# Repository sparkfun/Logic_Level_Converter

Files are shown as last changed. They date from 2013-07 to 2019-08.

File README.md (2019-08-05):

**NOTE:** *This product has been retired from our catalog. For a more up-to-date version, try looking at the [bi-directional logic level converter](https://www.sparkfun.com/products/12009).*

*If you are looking for more up-to-date info, please check out some of these resources to see how other users are still hacking and improving on this product.*

* *[SparkFun Forum](https://forum.sparkfun.com/)*
* *[Comments Here on GitHub](https://github.com/sparkfun/Logic_Level_Converter/issues)*
* *[IRC Channel](https://www.sparkfun.com/news/263)*

Logic Level Converter
=====================

Logic Level Converter (https://www.sparkfun.com/products/11978)

[*Logic Level Converter*](https://www.sparkfun.com/products/11978)

Design files for the [Logic Level Converter board](https://www.sparkfun.com/products/11978).

Repository Contents
-------------------

* **/hardware** - Eagle PCB layout files
* **/Production Files** - Files to support SparkFun production

Documentation
--------------
* **[Hookup Guide](https://learn.sparkfun.com/tutorials/retired---using-the-logic-level-converter)** - Basic hookup guide

License Information
-------------------

All contents of this repository are released under [Creative Commons Share-alike 3.0](http://creativecommons.org/licenses/by-sa/3.0/).

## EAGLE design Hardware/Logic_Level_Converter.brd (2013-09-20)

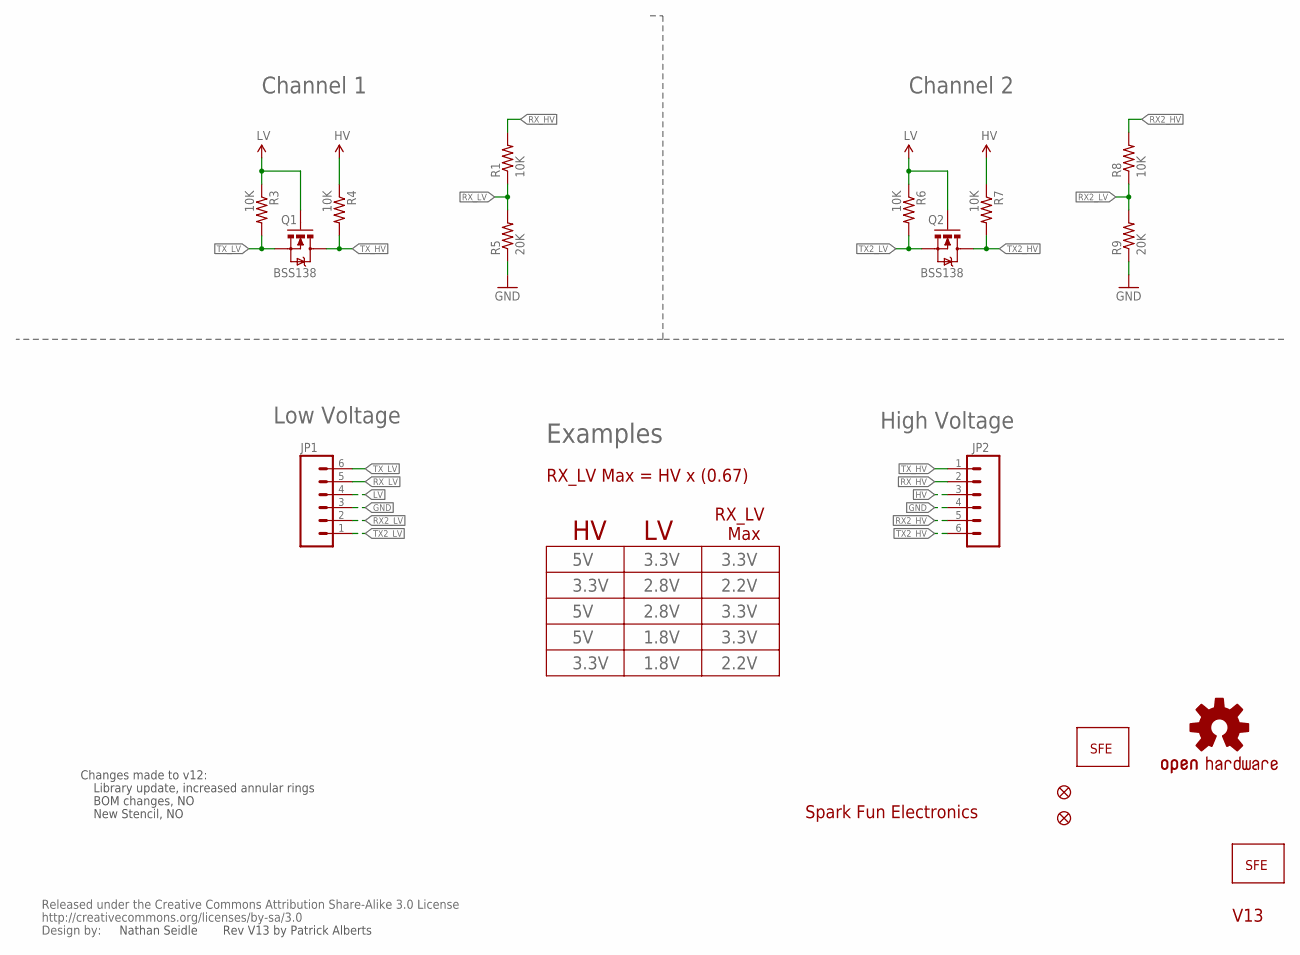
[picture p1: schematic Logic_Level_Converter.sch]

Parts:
CC_TEXT1: CREATIVE_COMMONS
JP1, JP2: M06SIP; 1X06
JP3, JP4: FIDUCIALUFIDUCIAL; MICRO-FIDUCIAL
JP5: LOGO-SFENW2; SFE-NEW-WEB
Q1, Q2: BSS138; SOT23-3
R1, R3, R4, R6, R7, R8: 10K; 0603-RES
R5, R9: 20K; 0603-RES
U$1: LOGO-SFESK; SFE-LOGO-FLAME
U$2: OSHW-LOGOS; OSHW-LOGO-S

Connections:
GND: JP1.3, JP2.4, R5.1, R9.1
HV: JP2.3, R4.1, R7.1
LV: JP1.4, Q1.1 (G), Q2.1 (G), R3.1, R6.1
RX2_HV: JP2.5, R8.2
RX2_LV: JP1.2, R8.1, R9.2
RX_HV: JP2.2, R1.2
RX_LV: JP1.5, R1.1, R5.2
TX2_HV: JP2.6, Q2.3 (D), R7.2
TX2_LV: JP1.1, Q2.2 (S), R6.2
TX_HV: JP2.1, Q1.3 (D), R4.2
TX_LV: JP1.6, Q1.2 (S), R3.2

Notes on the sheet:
Spark Fun Electronics
Channel 1
Channel 2
High Voltage
Low Voltage
Examples
RX_LV
Max
3.3V
2.8V
2.2V
1.8V
Changes made to v12:
Library update, increased annular rings
BOM changes, NO
New Stencil, NO
V13
RX_LV Max = HV x (0.67)
Nathan Seidle
Rev V13 by Patrick Alberts

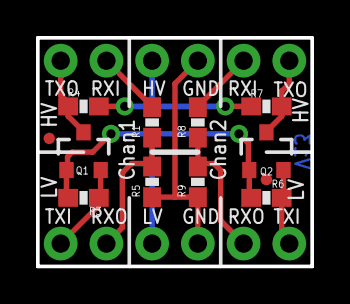
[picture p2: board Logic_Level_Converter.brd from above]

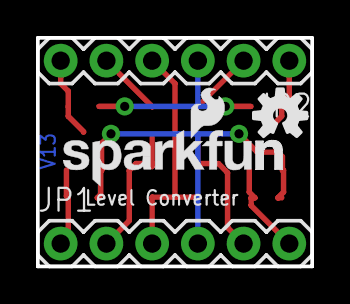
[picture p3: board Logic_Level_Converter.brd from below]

Board: 2 copper layers, 15.2 x 12.7 mm, 18 parts (5 on the bottom side), 11 nets.

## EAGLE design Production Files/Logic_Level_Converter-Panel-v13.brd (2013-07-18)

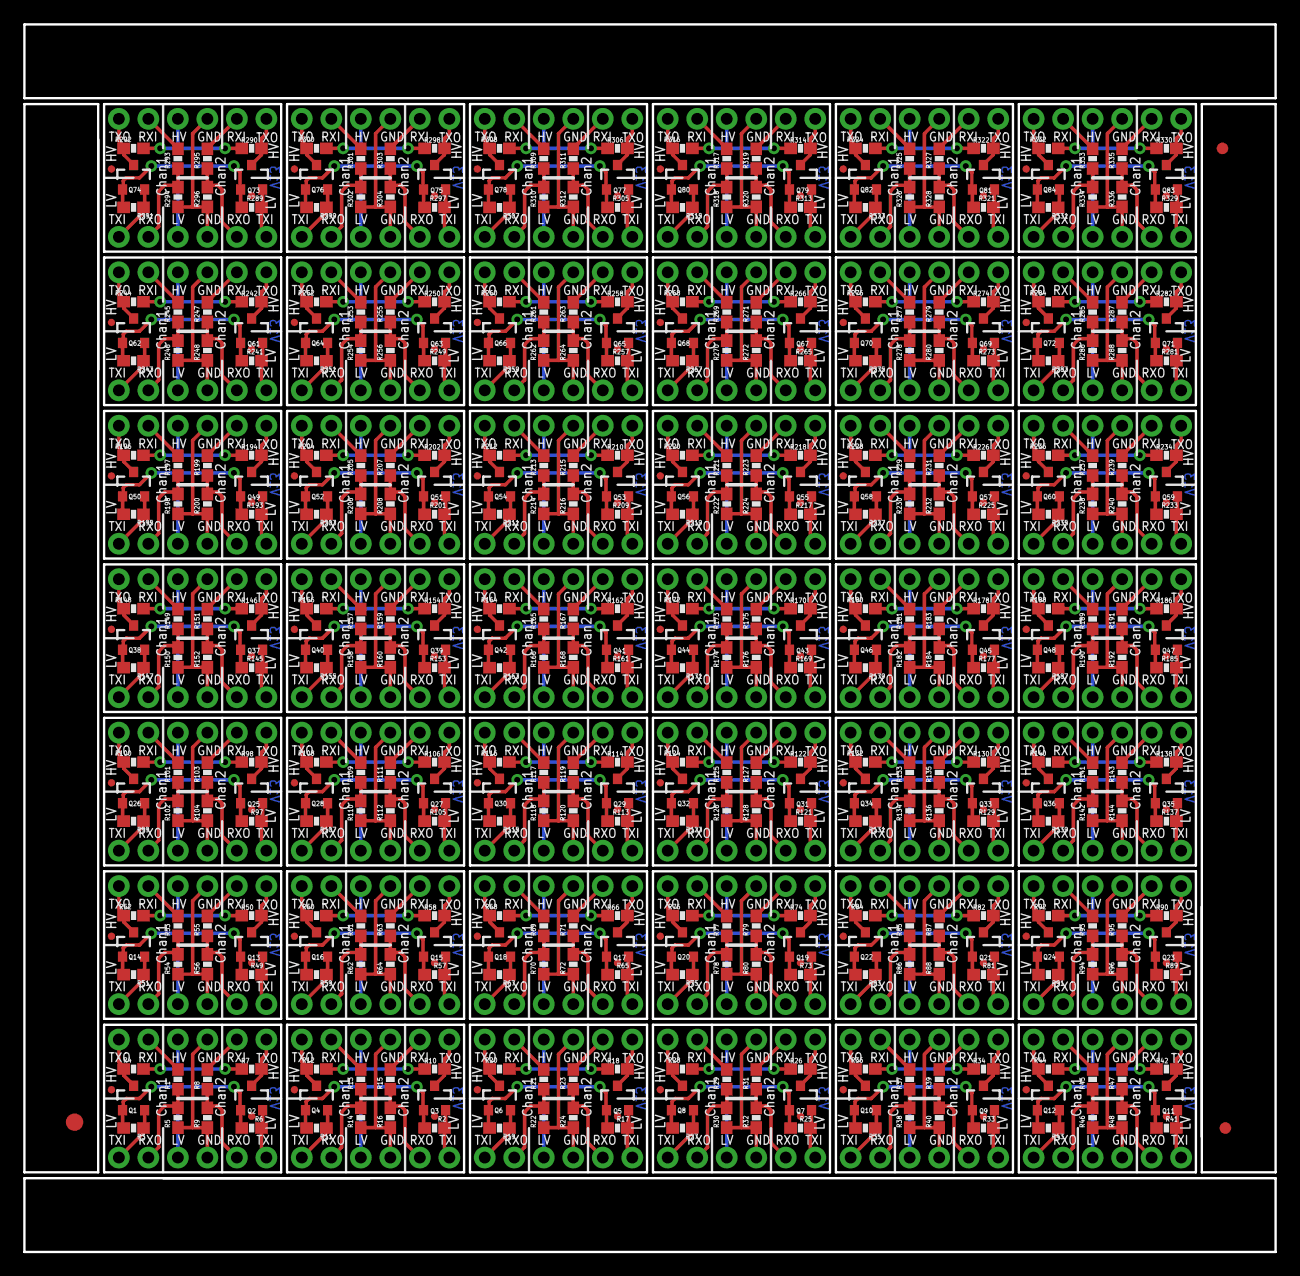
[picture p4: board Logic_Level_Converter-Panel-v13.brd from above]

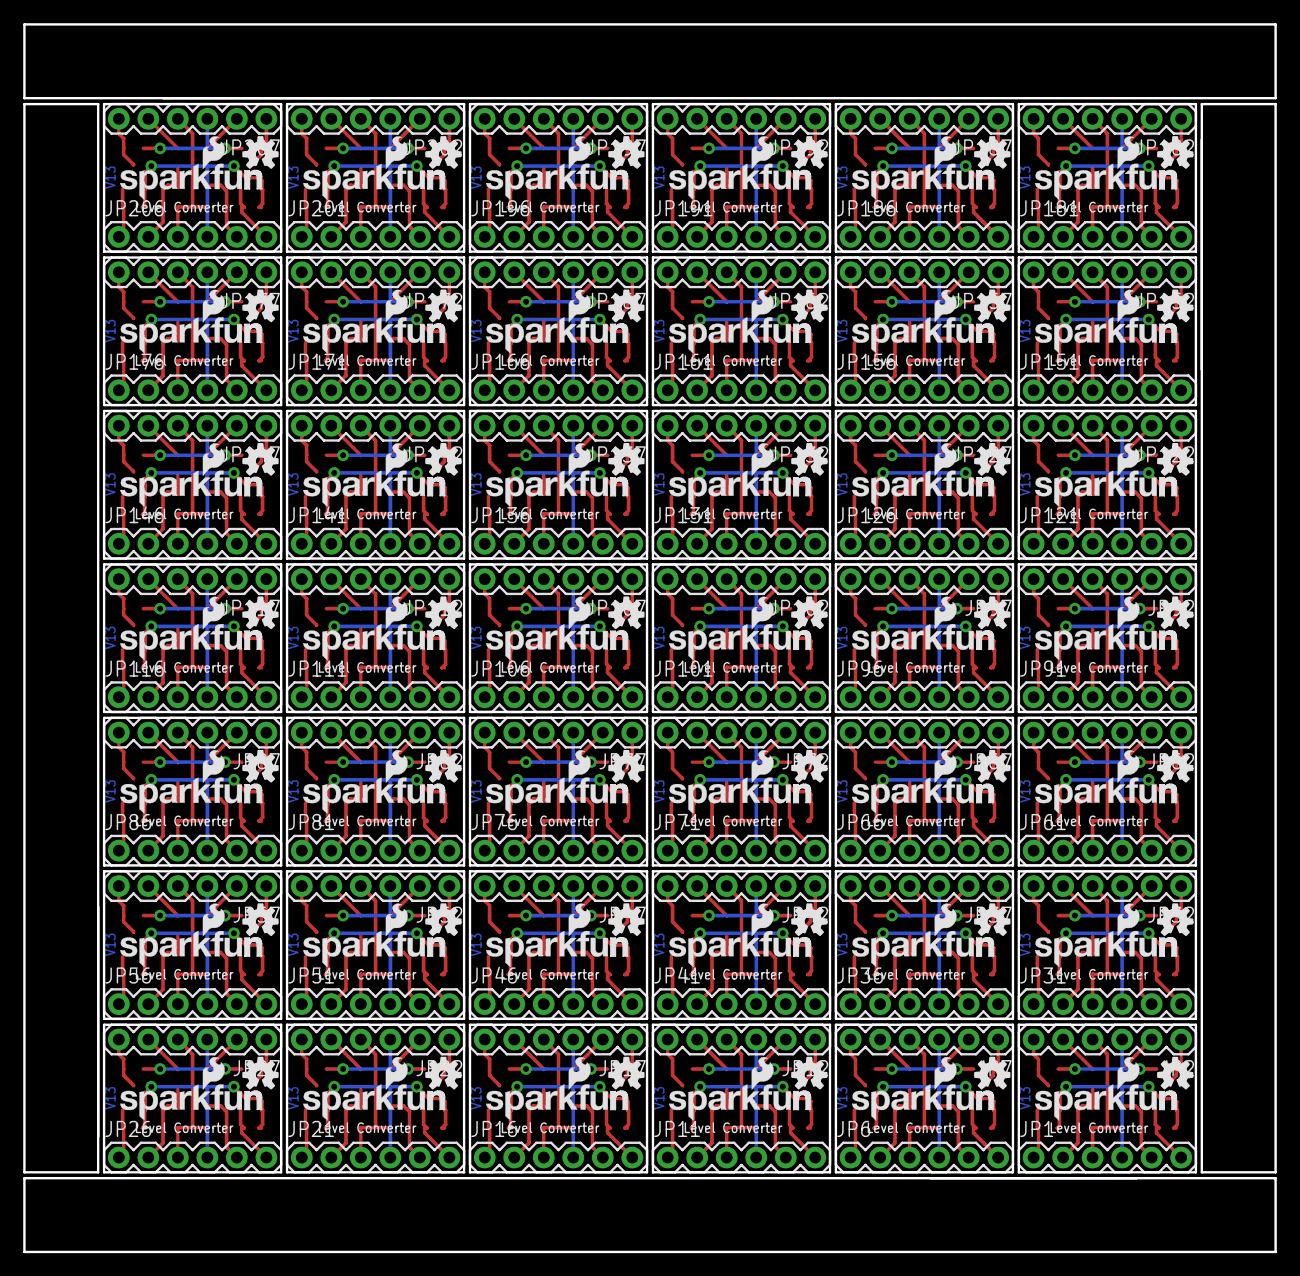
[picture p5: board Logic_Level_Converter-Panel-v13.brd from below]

Board: 2 copper layers, 107.7 x 105.7 mm, 717 parts (210 on the bottom side), 462 nets.

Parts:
E$1: FIDUCIAL-1.5X3
E$4, E$5: FIDUCIAL-1X2
JP1, JP2, JP6, JP7, JP11, JP12, JP16, JP17, JP21, JP22, JP26, JP27, JP31, JP32, JP36, JP37, JP41, JP42, JP46, JP47, JP51, JP52, JP56, JP57, JP61, JP62, JP66, JP67, JP71, JP72, JP76, JP77, JP81, JP82, JP86, JP87, JP91, JP92, JP96, JP97, JP101, JP102, JP106, JP107, JP111, JP112, JP116, JP117, JP121, JP122, JP126, JP127, JP131, JP132, JP136, JP137, JP141, JP142, JP146, JP147, JP151, JP152, JP156, JP157, JP161, JP162, JP166, JP167, JP171, JP172, JP176, JP177, JP181, JP182, JP186, JP187, JP191, JP192, JP196, JP197, JP201, JP202, JP206, JP207: 1X06
JP3, JP4, JP8, JP9, JP13, JP14, JP18, JP19, JP23, JP24, JP28, JP29, JP33, JP34, JP38, JP39, JP43, JP44, JP48, JP49, JP53, JP54, JP58, JP59, JP63, JP64, JP68, JP69, JP73, JP74, JP78, JP79, JP83, JP84, JP88, JP89, JP93, JP94, JP98, JP99, JP103, JP104, JP108, JP109, JP113, JP114, JP118, JP119, JP123, JP124, JP128, JP129, JP133, JP134, JP138, JP139, JP143, JP144, JP148, JP149, JP153, JP154, JP158, JP159, JP163, JP164, JP168, JP169, JP173, JP174, JP178, JP179, JP183, JP184, JP188, JP189, JP193, JP194, JP198, JP199, JP203, JP204, JP208, JP209: FIDUCIALUFIDUCIAL; MICRO-FIDUCIAL
JP5, JP10, JP15, JP20, JP25, JP30, JP35, JP40, JP45, JP50, JP55, JP60, JP65, JP70, JP75, JP80, JP85, JP90, JP95, JP100, JP105, JP110, JP115, JP120, JP125, JP130, JP135, JP140, JP145, JP150, JP155, JP160, JP165, JP170, JP175, JP180, JP185, JP190, JP195, JP200, JP205, JP210: LOGO-SFENW2; SFE-NEW-WEB
Q1, Q2, Q3, Q4, Q5, Q6, Q7, Q8, Q9, Q10, Q11, Q12, Q13, Q14, Q15, Q16, Q17, Q18, Q19, Q20, Q21, Q22, Q23, Q24, Q25, Q26, Q27, Q28, Q29, Q30, Q31, Q32, Q33, Q34, Q35, Q36, Q37, Q38, Q39, Q40, Q41, Q42, Q43, Q44, Q45, Q46, Q47, Q48, Q49, Q50, Q51, Q52, Q53, Q54, Q55, Q56, Q57, Q58, Q59, Q60, Q61, Q62, Q63, Q64, Q65, Q66, Q67, Q68, Q69, Q70, Q71, Q72, Q73, Q74, Q75, Q76, Q77, Q78, Q79, Q80, Q81, Q82, Q83, Q84: BSS138; SOT23-3
R1, R2, R3, R4, R6, R7, R8, R10, R11, R12, R13, R15, R17, R18, R19, R20, R21, R23, R25, R26, R27, R28, R29, R31, R33, R34, R35, R36, R37, R39, R41, R42, R43, R44, R45, R47, R49, R50, R51, R52, R53, R55, R57, R58, R59, R60, R61, R63, R65, R66, R67, R68, R69, R71, R73, R74, R75, R76, R77, R79, R81, R82, R83, R84, R85, R87, R89, R90, R91, R92, R93, R95, R97, R98, R99, R100, R101, R103, R105, R106, R107, R108, R109, R111, R113, R114, R115, R116, R117, R119, R121, R122, R123, R124, R125, R127, R129, R130, R131, R132, R133, R135, R137, R138, R139, R140, R141, R143, R145, R146, R147, R148, R149, R151, R153, R154, R155, R156, R157, R159, R161, R162, R163, R164, R165, R167, R169, R170, R171, R172, R173, R175, R177, R178, R179, R180, R181, R183, R185, R186, R187, R188, R189, R191, R193, R194, R195, R196, R197, R199, R201, R202, R203, R204, R205, R207, R209, R210, R211, R212, R213, R215, R217, R218, R219, R220, R221, R223, R225, R226, R227, R228, R229, R231, R233, R234, R235, R236, R237, R239, R241, R242, R243, R244, R245, R247, R249, R250, R251, R252, R253, R255, R257, R258, R259, R260, R261, R263, R265, R266, R267, R268, R269, R271, R273, R274, R275, R276, R277, R279, R281, R282, R283, R284, R285, R287, R289, R290, R291, R292, R293, R295, R297, R298, R299, R300, R301, R303, R305, R306, R307, R308, R309, R311, R313, R314, R315, R316, R317, R319, R321, R322, R323, R324, R325, R327, R329, R330, R331, R332, R333, R335: 10K; 0603-RES
R5, R9, R14, R16, R22, R24, R30, R32, R38, R40, R46, R48, R54, R56, R62, R64, R70, R72, R78, R80, R86, R88, R94, R96, R102, R104, R110, R112, R118, R120, R126, R128, R134, R136, R142, R144, R150, R152, R158, R160, R166, R168, R174, R176, R182, R184, R190, R192, R198, R200, R206, R208, R214, R216, R222, R224, R230, R232, R238, R240, R246, R248, R254, R256, R262, R264, R270, R272, R278, R280, R286, R288, R294, R296, R302, R304, R310, R312, R318, R320, R326, R328, R334, R336: 20K; 0603-RES
U$1, U$3, U$5, U$7, U$9, U$11, U$13, U$15, U$17, U$19, U$21, U$23, U$25, U$27, U$29, U$31, U$33, U$35, U$37, U$39, U$41, U$43, U$45, U$47, U$49, U$51, U$53, U$55, U$57, U$59, U$61, U$63, U$65, U$67, U$69, U$71, U$73, U$75, U$77, U$79, U$81, U$83: LOGO-SFESK; SFE-LOGO-FLAME
U$2, U$4, U$6, U$8, U$10, U$12, U$14, U$16, U$18, U$20, U$22, U$24, U$26, U$28, U$30, U$32, U$34, U$36, U$38, U$40, U$42, U$44, U$46, U$48, U$50, U$52, U$54, U$56, U$58, U$60, U$62, U$64, U$66, U$68, U$70, U$72, U$74, U$76, U$78, U$80, U$82, U$84: OSHW-LOGOS; OSHW-LOGO-S

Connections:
GND: JP1.3, JP2.4, R5.1, R9.1
GND1: JP6.3, JP7.4, R14.1, R16.1
GND2: JP11.3, JP12.4, R22.1, R24.1
GND3: JP16.3, JP17.4, R30.1, R32.1
GND4: JP21.3, JP22.4, R38.1, R40.1
GND5: JP26.3, JP27.4, R46.1, R48.1
GND6: JP31.3, JP32.4, R54.1, R56.1
GND7: JP36.3, JP37.4, R62.1, R64.1
GND8: JP41.3, JP42.4, R70.1, R72.1
GND9: JP46.3, JP47.4, R78.1, R80.1
GND10: JP51.3, JP52.4, R86.1, R88.1
GND11: JP56.3, JP57.4, R94.1, R96.1
GND12: JP61.3, JP62.4, R102.1, R104.1
GND13: JP66.3, JP67.4, R110.1, R112.1
GND14: JP71.3, JP72.4, R118.1, R120.1
GND15: JP76.3, JP77.4, R126.1, R128.1
GND16: JP81.3, JP82.4, R134.1, R136.1
GND17: JP86.3, JP87.4, R142.1, R144.1
GND18: JP91.3, JP92.4, R150.1, R152.1
GND19: JP96.3, JP97.4, R158.1, R160.1
GND20: JP101.3, JP102.4, R166.1, R168.1
GND21: JP106.3, JP107.4, R174.1, R176.1
GND22: JP111.3, JP112.4, R182.1, R184.1
GND23: JP116.3, JP117.4, R190.1, R192.1
GND24: JP121.3, JP122.4, R198.1, R200.1
GND25: JP126.3, JP127.4, R206.1, R208.1
GND26: JP131.3, JP132.4, R214.1, R216.1
GND27: JP136.3, JP137.4, R222.1, R224.1
GND28: JP141.3, JP142.4, R230.1, R232.1
GND29: JP146.3, JP147.4, R238.1, R240.1
GND30: JP151.3, JP152.4, R246.1, R248.1
GND31: JP156.3, JP157.4, R254.1, R256.1
GND32: JP161.3, JP162.4, R262.1, R264.1
GND33: JP166.3, JP167.4, R270.1, R272.1
GND34: JP171.3, JP172.4, R278.1, R280.1
GND35: JP176.3, JP177.4, R286.1, R288.1
GND36: JP181.3, JP182.4, R294.1, R296.1
GND37: JP186.3, JP187.4, R302.1, R304.1
GND38: JP191.3, JP192.4, R310.1, R312.1
GND39: JP196.3, JP197.4, R318.1, R320.1
GND40: JP201.3, JP202.4, R326.1, R328.1
GND41: JP206.3, JP207.4, R334.1, R336.1
HV: JP2.3, R4.1, R7.1
HV1: JP7.3, R10.1, R12.1
HV2: JP12.3, R18.1, R20.1
HV3: JP17.3, R26.1, R28.1
HV4: JP22.3, R34.1, R36.1
HV5: JP27.3, R42.1, R44.1
HV6: JP32.3, R50.1, R52.1
HV7: JP37.3, R58.1, R60.1
HV8: JP42.3, R66.1, R68.1
HV9: JP47.3, R74.1, R76.1
HV10: JP52.3, R82.1, R84.1
HV11: JP57.3, R90.1, R92.1
HV12: JP62.3, R98.1, R100.1
HV13: JP67.3, R106.1, R108.1
HV14: JP72.3, R114.1, R116.1
HV15: JP77.3, R122.1, R124.1
HV16: JP82.3, R130.1, R132.1
HV17: JP87.3, R138.1, R140.1
HV18: JP92.3, R146.1, R148.1
HV19: JP97.3, R154.1, R156.1
HV20: JP102.3, R162.1, R164.1
HV21: JP107.3, R170.1, R172.1
HV22: JP112.3, R178.1, R180.1
HV23: JP117.3, R186.1, R188.1
HV24: JP122.3, R194.1, R196.1
HV25: JP127.3, R202.1, R204.1
HV26: JP132.3, R210.1, R212.1
HV27: JP137.3, R218.1, R220.1
HV28: JP142.3, R226.1, R228.1
HV29: JP147.3, R234.1, R236.1
HV30: JP152.3, R242.1, R244.1
HV31: JP157.3, R250.1, R252.1
HV32: JP162.3, R258.1, R260.1
HV33: JP167.3, R266.1, R268.1
HV34: JP172.3, R274.1, R276.1
HV35: JP177.3, R282.1, R284.1
HV36: JP182.3, R290.1, R292.1
HV37: JP187.3, R298.1, R300.1
HV38: JP192.3, R306.1, R308.1
HV39: JP197.3, R314.1, R316.1
HV40: JP202.3, R322.1, R324.1
HV41: JP207.3, R330.1, R332.1
LV: JP1.4, Q1.1, Q2.1, R3.1, R6.1
LV1: JP6.4, Q3.1, Q4.1, R2.1, R11.1
LV2: JP11.4, Q5.1, Q6.1, R17.1, R19.1
LV3: JP16.4, Q7.1, Q8.1, R25.1, R27.1
LV4: JP21.4, Q9.1, Q10.1, R33.1, R35.1
LV5: JP26.4, Q11.1, Q12.1, R41.1, R43.1
LV6: JP31.4, Q13.1, Q14.1, R49.1, R51.1
LV7: JP36.4, Q15.1, Q16.1, R57.1, R59.1
LV8: JP41.4, Q17.1, Q18.1, R65.1, R67.1
LV9: JP46.4, Q19.1, Q20.1, R73.1, R75.1
LV10: JP51.4, Q21.1, Q22.1, R81.1, R83.1
LV11: JP56.4, Q23.1, Q24.1, R89.1, R91.1
LV12: JP61.4, Q25.1, Q26.1, R97.1, R99.1
LV13: JP66.4, Q27.1, Q28.1, R105.1, R107.1
LV14: JP71.4, Q29.1, Q30.1, R113.1, R115.1
LV15: JP76.4, Q31.1, Q32.1, R121.1, R123.1
LV16: JP81.4, Q33.1, Q34.1, R129.1, R131.1
LV17: JP86.4, Q35.1, Q36.1, R137.1, R139.1
LV18: JP91.4, Q37.1, Q38.1, R145.1, R147.1
LV19: JP96.4, Q39.1, Q40.1, R153.1, R155.1
LV20: JP101.4, Q41.1, Q42.1, R161.1, R163.1
LV21: JP106.4, Q43.1, Q44.1, R169.1, R171.1
LV22: JP111.4, Q45.1, Q46.1, R177.1, R179.1
LV23: JP116.4, Q47.1, Q48.1, R185.1, R187.1
LV24: JP121.4, Q49.1, Q50.1, R193.1, R195.1
LV25: JP126.4, Q51.1, Q52.1, R201.1, R203.1
LV26: JP131.4, Q53.1, Q54.1, R209.1, R211.1
LV27: JP136.4, Q55.1, Q56.1, R217.1, R219.1
LV28: JP141.4, Q57.1, Q58.1, R225.1, R227.1
LV29: JP146.4, Q59.1, Q60.1, R233.1, R235.1
LV30: JP151.4, Q61.1, Q62.1, R241.1, R243.1
LV31: JP156.4, Q63.1, Q64.1, R249.1, R251.1
LV32: JP161.4, Q65.1, Q66.1, R257.1, R259.1
LV33: JP166.4, Q67.1, Q68.1, R265.1, R267.1
LV34: JP171.4, Q69.1, Q70.1, R273.1, R275.1
LV35: JP176.4, Q71.1, Q72.1, R281.1, R283.1
LV36: JP181.4, Q73.1, Q74.1, R289.1, R291.1
LV37: JP186.4, Q75.1, Q76.1, R297.1, R299.1
LV38: JP191.4, Q77.1, Q78.1, R305.1, R307.1
LV39: JP196.4, Q79.1, Q80.1, R313.1, R315.1
LV40: JP201.4, Q81.1, Q82.1, R321.1, R323.1
LV41: JP206.4, Q83.1, Q84.1, R329.1, R331.1
RX2_HV: JP2.5, R8.2
RX2_HV1: JP7.5, R15.2
RX2_HV2: JP12.5, R23.2
RX2_HV3: JP17.5, R31.2
RX2_HV4: JP22.5, R39.2
RX2_HV5: JP27.5, R47.2
RX2_HV6: JP32.5, R55.2
RX2_HV7: JP37.5, R63.2
RX2_HV8: JP42.5, R71.2
RX2_HV9: JP47.5, R79.2
RX2_HV10: JP52.5, R87.2
RX2_HV11: JP57.5, R95.2
RX2_HV12: JP62.5, R103.2
RX2_HV13: JP67.5, R111.2
RX2_HV14: JP72.5, R119.2
RX2_HV15: JP77.5, R127.2
RX2_HV16: JP82.5, R135.2
RX2_HV17: JP87.5, R143.2
RX2_HV18: JP92.5, R151.2
RX2_HV19: JP97.5, R159.2
RX2_HV20: JP102.5, R167.2
RX2_HV21: JP107.5, R175.2
RX2_HV22: JP112.5, R183.2
RX2_HV23: JP117.5, R191.2
RX2_HV24: JP122.5, R199.2
RX2_HV25: JP127.5, R207.2
RX2_HV26: JP132.5, R215.2
RX2_HV27: JP137.5, R223.2
RX2_HV28: JP142.5, R231.2
RX2_HV29: JP147.5, R239.2
RX2_HV30: JP152.5, R247.2
RX2_HV31: JP157.5, R255.2
RX2_HV32: JP162.5, R263.2
RX2_HV33: JP167.5, R271.2
RX2_HV34: JP172.5, R279.2
RX2_HV35: JP177.5, R287.2
RX2_HV36: JP182.5, R295.2
RX2_HV37: JP187.5, R303.2
RX2_HV38: JP192.5, R311.2
RX2_HV39: JP197.5, R319.2
RX2_HV40: JP202.5, R327.2
RX2_HV41: JP207.5, R335.2
RX2_LV: JP1.2, R8.1, R9.2
RX2_LV1: JP6.2, R15.1, R16.2
RX2_LV2: JP11.2, R23.1, R24.2
RX2_LV3: JP16.2, R31.1, R32.2
RX2_LV4: JP21.2, R39.1, R40.2
RX2_LV5: JP26.2, R47.1, R48.2
RX2_LV6: JP31.2, R55.1, R56.2
RX2_LV7: JP36.2, R63.1, R64.2
RX2_LV8: JP41.2, R71.1, R72.2
RX2_LV9: JP46.2, R79.1, R80.2
RX2_LV10: JP51.2, R87.1, R88.2
RX2_LV11: JP56.2, R95.1, R96.2
RX2_LV12: JP61.2, R103.1, R104.2
RX2_LV13: JP66.2, R111.1, R112.2
RX2_LV14: JP71.2, R119.1, R120.2
RX2_LV15: JP76.2, R127.1, R128.2
RX2_LV16: JP81.2, R135.1, R136.2
RX2_LV17: JP86.2, R143.1, R144.2
RX2_LV18: JP91.2, R151.1, R152.2
RX2_LV19: JP96.2, R159.1, R160.2
RX2_LV20: JP101.2, R167.1, R168.2
RX2_LV21: JP106.2, R175.1, R176.2
RX2_LV22: JP111.2, R183.1, R184.2
RX2_LV23: JP116.2, R191.1, R192.2
RX2_LV24: JP121.2, R199.1, R200.2
RX2_LV25: JP126.2, R207.1, R208.2
RX2_LV26: JP131.2, R215.1, R216.2
RX2_LV27: JP136.2, R223.1, R224.2
RX2_LV28: JP141.2, R231.1, R232.2
RX2_LV29: JP146.2, R239.1, R240.2
RX2_LV30: JP151.2, R247.1, R248.2
RX2_LV31: JP156.2, R255.1, R256.2
RX2_LV32: JP161.2, R263.1, R264.2
RX2_LV33: JP166.2, R271.1, R272.2
RX2_LV34: JP171.2, R279.1, R280.2
RX2_LV35: JP176.2, R287.1, R288.2
RX2_LV36: JP181.2, R295.1, R296.2
RX2_LV37: JP186.2, R303.1, R304.2
RX2_LV38: JP191.2, R311.1, R312.2
RX2_LV39: JP196.2, R319.1, R320.2
RX2_LV40: JP201.2, R327.1, R328.2
RX2_LV41: JP206.2, R335.1, R336.2
RX_HV: JP2.2, R1.2
RX_HV1: JP7.2, R13.2
RX_HV2: JP12.2, R21.2
RX_HV3: JP17.2, R29.2
RX_HV4: JP22.2, R37.2
RX_HV5: JP27.2, R45.2
RX_HV6: JP32.2, R53.2
RX_HV7: JP37.2, R61.2
RX_HV8: JP42.2, R69.2
RX_HV9: JP47.2, R77.2
RX_HV10: JP52.2, R85.2
RX_HV11: JP57.2, R93.2
RX_HV12: JP62.2, R101.2
RX_HV13: JP67.2, R109.2
RX_HV14: JP72.2, R117.2
RX_HV15: JP77.2, R125.2
RX_HV16: JP82.2, R133.2
RX_HV17: JP87.2, R141.2
RX_HV18: JP92.2, R149.2
RX_HV19: JP97.2, R157.2
RX_HV20: JP102.2, R165.2
RX_HV21: JP107.2, R173.2
RX_HV22: JP112.2, R181.2
RX_HV23: JP117.2, R189.2
RX_HV24: JP122.2, R197.2
RX_HV25: JP127.2, R205.2
RX_HV26: JP132.2, R213.2
RX_HV27: JP137.2, R221.2
RX_HV28: JP142.2, R229.2
RX_HV29: JP147.2, R237.2
RX_HV30: JP152.2, R245.2
RX_HV31: JP157.2, R253.2
RX_HV32: JP162.2, R261.2
RX_HV33: JP167.2, R269.2
RX_HV34: JP172.2, R277.2
RX_HV35: JP177.2, R285.2
RX_HV36: JP182.2, R293.2
RX_HV37: JP187.2, R301.2
RX_HV38: JP192.2, R309.2
RX_HV39: JP197.2, R317.2
RX_HV40: JP202.2, R325.2
RX_HV41: JP207.2, R333.2
RX_LV: JP1.5, R1.1, R5.2
RX_LV1: JP6.5, R13.1, R14.2
RX_LV2: JP11.5, R21.1, R22.2
RX_LV3: JP16.5, R29.1, R30.2
RX_LV4: JP21.5, R37.1, R38.2
RX_LV5: JP26.5, R45.1, R46.2
RX_LV6: JP31.5, R53.1, R54.2
RX_LV7: JP36.5, R61.1, R62.2
RX_LV8: JP41.5, R69.1, R70.2
RX_LV9: JP46.5, R77.1, R78.2
RX_LV10: JP51.5, R85.1, R86.2
RX_LV11: JP56.5, R93.1, R94.2
RX_LV12: JP61.5, R101.1, R102.2
RX_LV13: JP66.5, R109.1, R110.2
RX_LV14: JP71.5, R117.1, R118.2
RX_LV15: JP76.5, R125.1, R126.2
RX_LV16: JP81.5, R133.1, R134.2
RX_LV17: JP86.5, R141.1, R142.2
RX_LV18: JP91.5, R149.1, R150.2
RX_LV19: JP96.5, R157.1, R158.2
RX_LV20: JP101.5, R165.1, R166.2
RX_LV21: JP106.5, R173.1, R174.2
RX_LV22: JP111.5, R181.1, R182.2
RX_LV23: JP116.5, R189.1, R190.2
RX_LV24: JP121.5, R197.1, R198.2
RX_LV25: JP126.5, R205.1, R206.2
RX_LV26: JP131.5, R213.1, R214.2
RX_LV27: JP136.5, R221.1, R222.2
RX_LV28: JP141.5, R229.1, R230.2
RX_LV29: JP146.5, R237.1, R238.2
RX_LV30: JP151.5, R245.1, R246.2
RX_LV31: JP156.5, R253.1, R254.2
RX_LV32: JP161.5, R261.1, R262.2
RX_LV33: JP166.5, R269.1, R270.2
RX_LV34: JP171.5, R277.1, R278.2
RX_LV35: JP176.5, R285.1, R286.2
RX_LV36: JP181.5, R293.1, R294.2
RX_LV37: JP186.5, R301.1, R302.2
RX_LV38: JP191.5, R309.1, R310.2
RX_LV39: JP196.5, R317.1, R318.2
RX_LV40: JP201.5, R325.1, R326.2
RX_LV41: JP206.5, R333.1, R334.2
TX2_HV: JP2.6, Q2.3, R7.2
TX2_HV1: JP7.6, Q3.3, R10.2
TX2_HV2: JP12.6, Q5.3, R18.2
TX2_HV3: JP17.6, Q7.3, R26.2
TX2_HV4: JP22.6, Q9.3, R34.2
TX2_HV5: JP27.6, Q11.3, R42.2
TX2_HV6: JP32.6, Q13.3, R50.2
TX2_HV7: JP37.6, Q15.3, R58.2
TX2_HV8: JP42.6, Q17.3, R66.2
TX2_HV9: JP47.6, Q19.3, R74.2
TX2_HV10: JP52.6, Q21.3, R82.2
TX2_HV11: JP57.6, Q23.3, R90.2
TX2_HV12: JP62.6, Q25.3, R98.2
TX2_HV13: JP67.6, Q27.3, R106.2
TX2_HV14: JP72.6, Q29.3, R114.2
TX2_HV15: JP77.6, Q31.3, R122.2
TX2_HV16: JP82.6, Q33.3, R130.2
TX2_HV17: JP87.6, Q35.3, R138.2
TX2_HV18: JP92.6, Q37.3, R146.2
TX2_HV19: JP97.6, Q39.3, R154.2
TX2_HV20: JP102.6, Q41.3, R162.2
TX2_HV21: JP107.6, Q43.3, R170.2
TX2_HV22: JP112.6, Q45.3, R178.2
TX2_HV23: JP117.6, Q47.3, R186.2
TX2_HV24: JP122.6, Q49.3, R194.2
TX2_HV25: JP127.6, Q51.3, R202.2
TX2_HV26: JP132.6, Q53.3, R210.2
TX2_HV27: JP137.6, Q55.3, R218.2
TX2_HV28: JP142.6, Q57.3, R226.2
TX2_HV29: JP147.6, Q59.3, R234.2
TX2_HV30: JP152.6, Q61.3, R242.2
TX2_HV31: JP157.6, Q63.3, R250.2
TX2_HV32: JP162.6, Q65.3, R258.2
TX2_HV33: JP167.6, Q67.3, R266.2
TX2_HV34: JP172.6, Q69.3, R274.2
TX2_HV35: JP177.6, Q71.3, R282.2
TX2_HV36: JP182.6, Q73.3, R290.2
TX2_HV37: JP187.6, Q75.3, R298.2
TX2_HV38: JP192.6, Q77.3, R306.2
TX2_HV39: JP197.6, Q79.3, R314.2
TX2_HV40: JP202.6, Q81.3, R322.2
TX2_HV41: JP207.6, Q83.3, R330.2
TX2_LV: JP1.1, Q2.2, R6.2
TX2_LV1: JP6.1, Q3.2, R2.2
TX2_LV2: JP11.1, Q5.2, R17.2
TX2_LV3: JP16.1, Q7.2, R25.2
TX2_LV4: JP21.1, Q9.2, R33.2
TX2_LV5: JP26.1, Q11.2, R41.2
TX2_LV6: JP31.1, Q13.2, R49.2
TX2_LV7: JP36.1, Q15.2, R57.2
TX2_LV8: JP41.1, Q17.2, R65.2
TX2_LV9: JP46.1, Q19.2, R73.2
TX2_LV10: JP51.1, Q21.2, R81.2
TX2_LV11: JP56.1, Q23.2, R89.2
TX2_LV12: JP61.1, Q25.2, R97.2
TX2_LV13: JP66.1, Q27.2, R105.2
TX2_LV14: JP71.1, Q29.2, R113.2
TX2_LV15: JP76.1, Q31.2, R121.2
TX2_LV16: JP81.1, Q33.2, R129.2
TX2_LV17: JP86.1, Q35.2, R137.2
TX2_LV18: JP91.1, Q37.2, R145.2
TX2_LV19: JP96.1, Q39.2, R153.2
TX2_LV20: JP101.1, Q41.2, R161.2
TX2_LV21: JP106.1, Q43.2, R169.2
TX2_LV22: JP111.1, Q45.2, R177.2
TX2_LV23: JP116.1, Q47.2, R185.2
TX2_LV24: JP121.1, Q49.2, R193.2
TX2_LV25: JP126.1, Q51.2, R201.2
TX2_LV26: JP131.1, Q53.2, R209.2
TX2_LV27: JP136.1, Q55.2, R217.2
TX2_LV28: JP141.1, Q57.2, R225.2
TX2_LV29: JP146.1, Q59.2, R233.2
TX2_LV30: JP151.1, Q61.2, R241.2
TX2_LV31: JP156.1, Q63.2, R249.2
TX2_LV32: JP161.1, Q65.2, R257.2
TX2_LV33: JP166.1, Q67.2, R265.2
TX2_LV34: JP171.1, Q69.2, R273.2
TX2_LV35: JP176.1, Q71.2, R281.2
TX2_LV36: JP181.1, Q73.2, R289.2
TX2_LV37: JP186.1, Q75.2, R297.2
TX2_LV38: JP191.1, Q77.2, R305.2
TX2_LV39: JP196.1, Q79.2, R313.2
TX2_LV40: JP201.1, Q81.2, R321.2
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

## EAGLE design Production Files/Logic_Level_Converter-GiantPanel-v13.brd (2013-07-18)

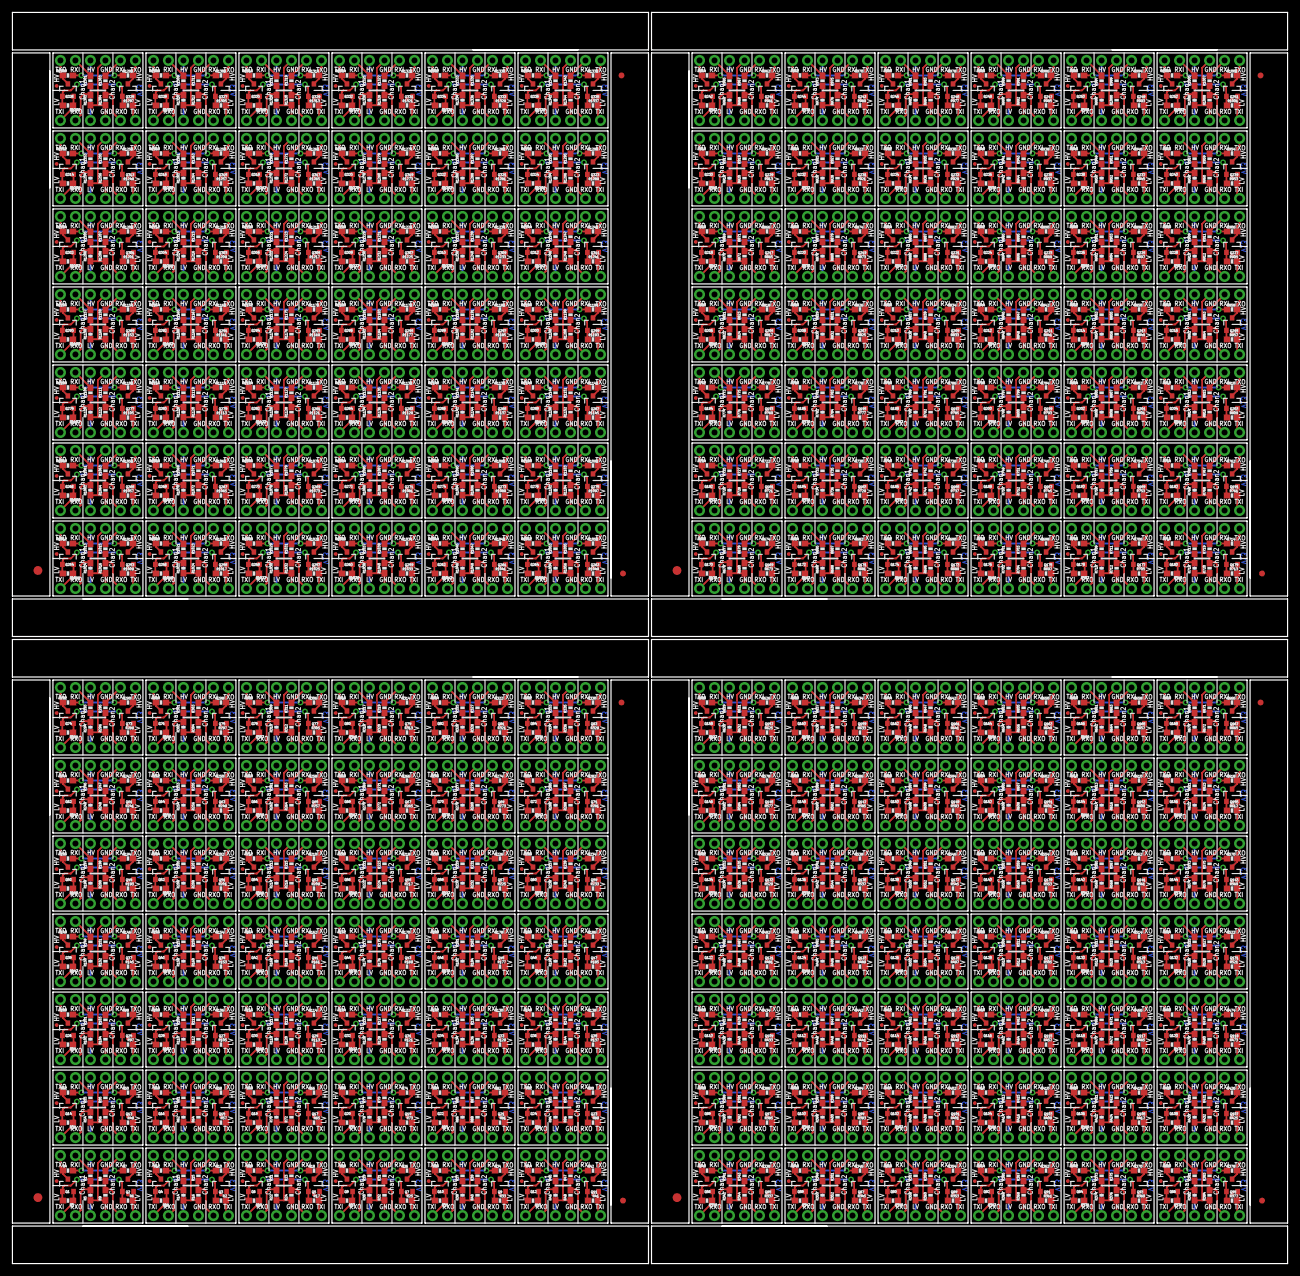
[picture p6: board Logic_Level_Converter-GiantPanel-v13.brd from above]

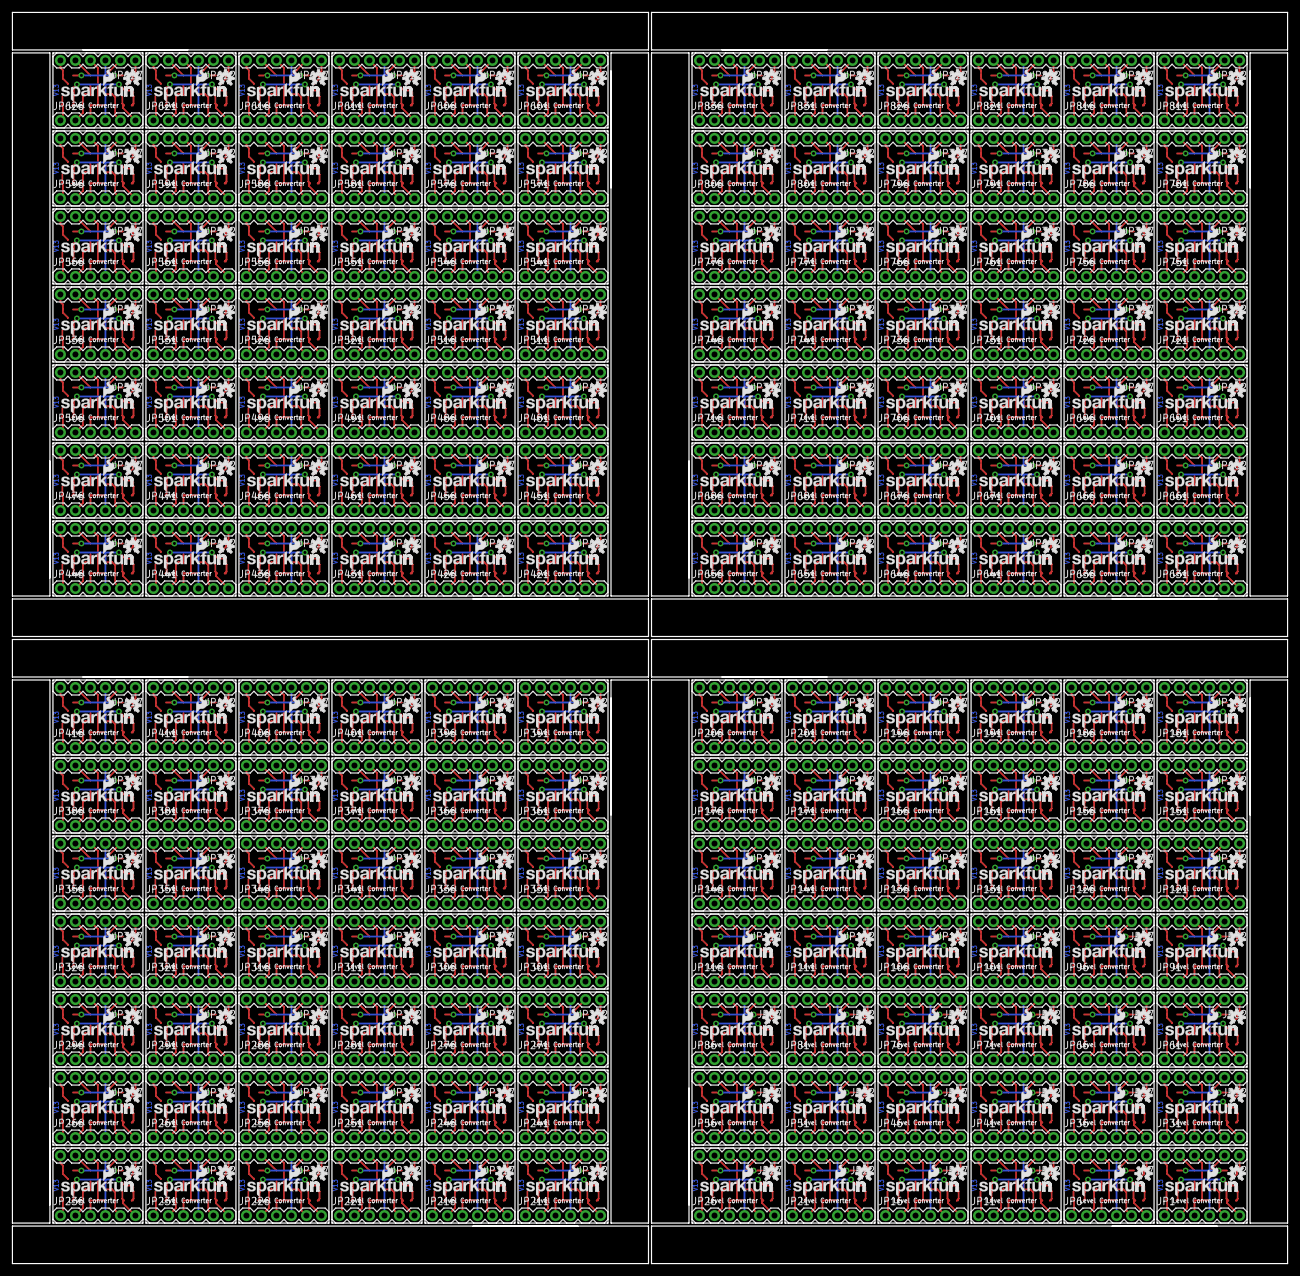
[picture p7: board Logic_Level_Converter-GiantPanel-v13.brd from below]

Board: 2 copper layers, 215.9 x 211.8 mm, 2868 parts (840 on the bottom side), 1848 nets.

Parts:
E$1, E$6, E$9, E$12: FIDUCIAL-1.5X3
E$2, E$3, E$4, E$5, E$7, E$8, E$10, E$11: FIDUCIAL-1X2
JP1, JP2, JP6, JP7, JP11, JP12, JP16, JP17, JP21, JP22, JP26, JP27, JP31, JP32, JP36, JP37, JP41, JP42, JP46, JP47, JP51, JP52, JP56, JP57, JP61, JP62, JP66, JP67, JP71, JP72, JP76, JP77, JP81, JP82, JP86, JP87, JP91, JP92, JP96, JP97, JP101, JP102, JP106, JP107, JP111, JP112, JP116, JP117, JP121, JP122, JP126, JP127, JP131, JP132, JP136, JP137, JP141, JP142, JP146, JP147, JP151, JP152, JP156, JP157, JP161, JP162, JP166, JP167, JP171, JP172, JP176, JP177, JP181, JP182, JP186, JP187, JP191, JP192, JP196, JP197, JP201, JP202, JP206, JP207, JP211, JP212, JP216, JP217, JP221, JP222, JP226, JP227, JP231, JP232, JP236, JP237, JP241, JP242, JP246, JP247, JP251, JP252, JP256, JP257, JP261, JP262, JP266, JP267, JP271, JP272, JP276, JP277, JP281, JP282, JP286, JP287, JP291, JP292, JP296, JP297, JP301, JP302, JP306, JP307, JP311, JP312, JP316, JP317, JP321, JP322, JP326, JP327, JP331, JP332, JP336, JP337, JP341, JP342, JP346, JP347, JP351, JP352, JP356, JP357, JP361, JP362, JP366, JP367, JP371, JP372, JP376, JP377, JP381, JP382, JP386, JP387, JP391, JP392, JP396, JP397, JP401, JP402, JP406, JP407, JP411, JP412, JP416, JP417, JP421, JP422, JP426, JP427, JP431, JP432, JP436, JP437, JP441, JP442, JP446, JP447, JP451, JP452, JP456, JP457, JP461, JP462, JP466, JP467, JP471, JP472, JP476, JP477, JP481, JP482, JP486, JP487, JP491, JP492, JP496, JP497, JP501, JP502, JP506, JP507, JP511, JP512, JP516, JP517, JP521, JP522, JP526, JP527, JP531, JP532, JP536, JP537, JP541, JP542, JP546, JP547, JP551, JP552, JP556, JP557, JP561, JP562, JP566, JP567, JP571, JP572, JP576, JP577, JP581, JP582, JP586, JP587, JP591, JP592, JP596, JP597, JP601, JP602, JP606, JP607, JP611, JP612, JP616, JP617, JP621, JP622, JP626, JP627, JP631, JP632, JP636, JP637, JP641, JP642, JP646, JP647, JP651, JP652, JP656, JP657, JP661, JP662, JP666, JP667, JP671, JP672, JP676, JP677, JP681, JP682, JP686, JP687, JP691, JP692, JP696, JP697, JP701, JP702, JP706, JP707, JP711, JP712, JP716, JP717, JP721, JP722, JP726, JP727, JP731, JP732, JP736, JP737, JP741, JP742, JP746, JP747, JP751, JP752, JP756, JP757, JP761, JP762, JP766, JP767, JP771, JP772, JP776, JP777, JP781, JP782, JP786, JP787, JP791, JP792, JP796, JP797, JP801, JP802, JP806, JP807, JP811, JP812, JP816, JP817, JP821, JP822, JP826, JP827, JP831, JP832, JP836, JP837: 1X06
JP3, JP4, JP8, JP9, JP13, JP14, JP18, JP19, JP23, JP24, JP28, JP29, JP33, JP34, JP38, JP39, JP43, JP44, JP48, JP49, JP53, JP54, JP58, JP59, JP63, JP64, JP68, JP69, JP73, JP74, JP78, JP79, JP83, JP84, JP88, JP89, JP93, JP94, JP98, JP99, JP103, JP104, JP108, JP109, JP113, JP114, JP118, JP119, JP123, JP124, JP128, JP129, JP133, JP134, JP138, JP139, JP143, JP144, JP148, JP149, JP153, JP154, JP158, JP159, JP163, JP164, JP168, JP169, JP173, JP174, JP178, JP179, JP183, JP184, JP188, JP189, JP193, JP194, JP198, JP199, JP203, JP204, JP208, JP209, JP213, JP214, JP218, JP219, JP223, JP224, JP228, JP229, JP233, JP234, JP238, JP239, JP243, JP244, JP248, JP249, JP253, JP254, JP258, JP259, JP263, JP264, JP268, JP269, JP273, JP274, JP278, JP279, JP283, JP284, JP288, JP289, JP293, JP294, JP298, JP299, JP303, JP304, JP308, JP309, JP313, JP314, JP318, JP319, JP323, JP324, JP328, JP329, JP333, JP334, JP338, JP339, JP343, JP344, JP348, JP349, JP353, JP354, JP358, JP359, JP363, JP364, JP368, JP369, JP373, JP374, JP378, JP379, JP383, JP384, JP388, JP389, JP393, JP394, JP398, JP399, JP403, JP404, JP408, JP409, JP413, JP414, JP418, JP419, JP423, JP424, JP428, JP429, JP433, JP434, JP438, JP439, JP443, JP444, JP448, JP449, JP453, JP454, JP458, JP459, JP463, JP464, JP468, JP469, JP473, JP474, JP478, JP479, JP483, JP484, JP488, JP489, JP493, JP494, JP498, JP499, JP503, JP504, JP508, JP509, JP513, JP514, JP518, JP519, JP523, JP524, JP528, JP529, JP533, JP534, JP538, JP539, JP543, JP544, JP548, JP549, JP553, JP554, JP558, JP559, JP563, JP564, JP568, JP569, JP573, JP574, JP578, JP579, JP583, JP584, JP588, JP589, JP593, JP594, JP598, JP599, JP603, JP604, JP608, JP609, JP613, JP614, JP618, JP619, JP623, JP624, JP628, JP629, JP633, JP634, JP638, JP639, JP643, JP644, JP648, JP649, JP653, JP654, JP658, JP659, JP663, JP664, JP668, JP669, JP673, JP674, JP678, JP679, JP683, JP684, JP688, JP689, JP693, JP694, JP698, JP699, JP703, JP704, JP708, JP709, JP713, JP714, JP718, JP719, JP723, JP724, JP728, JP729, JP733, JP734, JP738, JP739, JP743, JP744, JP748, JP749, JP753, JP754, JP758, JP759, JP763, JP764, JP768, JP769, JP773, JP774, JP778, JP779, JP783, JP784, JP788, JP789, JP793, JP794, JP798, JP799, JP803, JP804, JP808, JP809, JP813, JP814, JP818, JP819, JP823, JP824, JP828, JP829, JP833, JP834, JP838, JP839: FIDUCIALUFIDUCIAL; MICRO-FIDUCIAL
JP5, JP10, JP15, JP20, JP25, JP30, JP35, JP40, JP45, JP50, JP55, JP60, JP65, JP70, JP75, JP80, JP85, JP90, JP95, JP100, JP105, JP110, JP115, JP120, JP125, JP130, JP135, JP140, JP145, JP150, JP155, JP160, JP165, JP170, JP175, JP180, JP185, JP190, JP195, JP200, JP205, JP210, JP215, JP220, JP225, JP230, JP235, JP240, JP245, JP250, JP255, JP260, JP265, JP270, JP275, JP280, JP285, JP290, JP295, JP300, JP305, JP310, JP315, JP320, JP325, JP330, JP335, JP340, JP345, JP350, JP355, JP360, JP365, JP370, JP375, JP380, JP385, JP390, JP395, JP400, JP405, JP410, JP415, JP420, JP425, JP430, JP435, JP440, JP445, JP450, JP455, JP460, JP465, JP470, JP475, JP480, JP485, JP490, JP495, JP500, JP505, JP510, JP515, JP520, JP525, JP530, JP535, JP540, JP545, JP550, JP555, JP560, JP565, JP570, JP575, JP580, JP585, JP590, JP595, JP600, JP605, JP610, JP615, JP620, JP625, JP630, JP635, JP640, JP645, JP650, JP655, JP660, JP665, JP670, JP675, JP680, JP685, JP690, JP695, JP700, JP705, JP710, JP715, JP720, JP725, JP730, JP735, JP740, JP745, JP750, JP755, JP760, JP765, JP770, JP775, JP780, JP785, JP790, JP795, JP800, JP805, JP810, JP815, JP820, JP825, JP830, JP835, JP840: LOGO-SFENW2; SFE-NEW-WEB
Q1, Q2, Q3, Q4, Q5, Q6, Q7, Q8, Q9, Q10, Q11, Q12, Q13, Q14, Q15, Q16, Q17, Q18, Q19, Q20, Q21, Q22, Q23, Q24, Q25, Q26, Q27, Q28, Q29, Q30, Q31, Q32, Q33, Q34, Q35, Q36, Q37, Q38, Q39, Q40, Q41, Q42, Q43, Q44, Q45, Q46, Q47, Q48, Q49, Q50, Q51, Q52, Q53, Q54, Q55, Q56, Q57, Q58, Q59, Q60, Q61, Q62, Q63, Q64, Q65, Q66, Q67, Q68, Q69, Q70, Q71, Q72, Q73, Q74, Q75, Q76, Q77, Q78, Q79, Q80, Q81, Q82, Q83, Q84, Q85, Q86, Q87, Q88, Q89, Q90, Q91, Q92, Q93, Q94, Q95, Q96, Q97, Q98, Q99, Q100, Q101, Q102, Q103, Q104, Q105, Q106, Q107, Q108, Q109, Q110, Q111, Q112, Q113, Q114, Q115, Q116, Q117, Q118, Q119, Q120, Q121, Q122, Q123, Q124, Q125, Q126, Q127, Q128, Q129, Q130, Q131, Q132, Q133, Q134, Q135, Q136, Q137, Q138, Q139, Q140, Q141, Q142, Q143, Q144, Q145, Q146, Q147, Q148, Q149, Q150, Q151, Q152, Q153, Q154, Q155, Q156, Q157, Q158, Q159, Q160, Q161, Q162, Q163, Q164, Q165, Q166, Q167, Q168, Q169, Q170, Q171, Q172, Q173, Q174, Q175, Q176, Q177, Q178, Q179, Q180, Q181, Q182, Q183, Q184, Q185, Q186, Q187, Q188, Q189, Q190, Q191, Q192, Q193, Q194, Q195, Q196, Q197, Q198, Q199, Q200, Q201, Q202, Q203, Q204, Q205, Q206, Q207, Q208, Q209, Q210, Q211, Q212, Q213, Q214, Q215, Q216, Q217, Q218, Q219, Q220, Q221, Q222, Q223, Q224, Q225, Q226, Q227, Q228, Q229, Q230, Q231, Q232, Q233, Q234, Q235, Q236, Q237, Q238, Q239, Q240, Q241, Q242, Q243, Q244, Q245, Q246, Q247, Q248, Q249, Q250, Q251, Q252, Q253, Q254, Q255, Q256, Q257, Q258, Q259, Q260, Q261, Q262, Q263, Q264, Q265, Q266, Q267, Q268, Q269, Q270, Q271, Q272, Q273, Q274, Q275, Q276, Q277, Q278, Q279, Q280, Q281, Q282, Q283, Q284, Q285, Q286, Q287, Q288, Q289, Q290, Q291, Q292, Q293, Q294, Q295, Q296, Q297, Q298, Q299, Q300, Q301, Q302, Q303, Q304, Q305, Q306, Q307, Q308, Q309, Q310, Q311, Q312, Q313, Q314, Q315, Q316, Q317, Q318, Q319, Q320, Q321, Q322, Q323, Q324, Q325, Q326, Q327, Q328, Q329, Q330, Q331, Q332, Q333, Q334, Q335, Q336: BSS138; SOT23-3
R1, R2, R3, R4, R6, R7, R8, R10, R11, R12, R13, R15, R17, R18, R19, R20, R21, R23, R25, R26, R27, R28, R29, R31, R33, R34, R35, R36, R37, R39, R41, R42, R43, R44, R45, R47, R49, R50, R51, R52, R53, R55, R57, R58, R59, R60, R61, R63, R65, R66, R67, R68, R69, R71, R73, R74, R75, R76, R77, R79, R81, R82, R83, R84, R85, R87, R89, R90, R91, R92, R93, R95, R97, R98, R99, R100, R101, R103, R105, R106, R107, R108, R109, R111, R113, R114, R115, R116, R117, R119, R121, R122, R123, R124, R125, R127, R129, R130, R131, R132, R133, R135, R137, R138, R139, R140, R141, R143, R145, R146, R147, R148, R149, R151, R153, R154, R155, R156, R157, R159, R161, R162, R163, R164, R165, R167, R169, R170, R171, R172, R173, R175, R177, R178, R179, R180, R181, R183, R185, R186, R187, R188, R189, R191, R193, R194, R195, R196, R197, R199, R201, R202, R203, R204, R205, R207, R209, R210, R211, R212, R213, R215, R217, R218, R219, R220, R221, R223, R225, R226, R227, R228, R229, R231, R233, R234, R235, R236, R237, R239, R241, R242, R243, R244, R245, R247, R249, R250, R251, R252, R253, R255, R257, R258, R259, R260, R261, R263, R265, R266, R267, R268, R269, R271, R273, R274, R275, R276, R277, R279, R281, R282, R283, R284, R285, R287, R289, R290, R291, R292, R293, R295, R297, R298, R299, R300, R301, R303, R305, R306, R307, R308, R309, R311, R313, R314, R315, R316, R317, R319, R321, R322, R323, R324, R325, R327, R329, R330, R331, R332, R333, R335, R337, R338, R339, R340, R341, R343, R345, R346, R347, R348, R349, R351, R353, R354, R355, R356, R357, R359, R361, R362, R363, R364, R365, R367, R369, R370, R371, R372, R373, R375, R377, R378, R379, R380, R381, R383, R385, R386, R387, R388, R389, R391, R393, R394, R395, R396, R397, R399, R401, R402, R403, R404, R405, R407, R409, R410, R411, R412, R413, R415, R417, R418, R419, R420, R421, R423, R425, R426, R427, R428, R429, R431, R433, R434, R435, R436, R437, R439, R441, R442, R443, R444, R445, R447, R449, R450, R451, R452, R453, R455, R457, R458, R459, R460, R461, R463, R465, R466, R467, R468, R469, R471, R473, R474, R475, R476, R477, R479, R481, R482, R483, R484, R485, R487, R489, R490, R491, R492, R493, R495, R497, R498, R499, R500, R501, R503, R505, R506, R507, R508, R509, R511, R513, R514, R515, R516, R517, R519, R521, R522, R523, R524, R525, R527, R529, R530, R531, R532, R533, R535, R537, R538, R539, R540, R541, R543, R545, R546, R547, R548, R549, R551, R553, R554, R555, R556, R557, R559, R561, R562, R563, R564, R565, R567, R569, R570, R571, R572, R573, R575, R577, R578, R579, R580, R581, R583, R585, R586, R587, R588, R589, R591, R593, R594, R595, R596, R597, R599, R601, R602, R603, R604, R605, R607, R609, R610, R611, R612, R613, R615, R617, R618, R619, R620, R621, R623, R625, R626, R627, R628, R629, R631, R633, R634, R635, R636, R637, R639, R641, R642, R643, R644, R645, R647, R649, R650, R651, R652, R653, R655, R657, R658, R659, R660, R661, R663, R665, R666, R667, R668, R669, R671, R673, R674, R675, R676, R677, R679, R681, R682, R683, R684, R685, R687, R689, R690, R691, R692, R693, R695, R697, R698, R699, R700, R701, R703, R705, R706, R707, R708, R709, R711, R713, R714, R715, R716, R717, R719, R721, R722, R723, R724, R725, R727, R729, R730, R731, R732, R733, R735, R737, R738, R739, R740, R741, R743, R745, R746, R747, R748, R749, R751, R753, R754, R755, R756, R757, R759, R761, R762, R763, R764, R765, R767, R769, R770, R771, R772, R773, R775, R777, R778, R779, R780, R781, R783, R785, R786, R787, R788, R789, R791, R793, R794, R795, R796, R797, R799, R801, R802, R803, R804, R805, R807, R809, R810, R811, R812, R813, R815, R817, R818, R819, R820, R821, R823, R825, R826, R827, R828, R829, R831, R833, R834, R835, R836, R837, R839, R841, R842, R843, R844, R845, R847, R849, R850, R851, R852, R853, R855, R857, R858, R859, R860, R861, R863, R865, R866, R867, R868, R869, R871, R873, R874, R875, R876, R877, R879, R881, R882, R883, R884, R885, R887, R889, R890, R891, R892, R893, R895, R897, R898, R899, R900, R901, R903, R905, R906, R907, R908, R909, R911, R913, R914, R915, R916, R917, R919, R921, R922, R923, R924, R925, R927, R929, R930, R931, R932, R933, R935, R937, R938, R939, R940, R941, R943, R945, R946, R947, R948, R949, R951, R953, R954, R955, R956, R957, R959, R961, R962, R963, R964, R965, R967, R969, R970, R971, R972, R973, R975, R977, R978, R979, R980, R981, R983, R985, R986, R987, R988, R989, R991, R993, R994, R995, R996, R997, R999, R1001, R1002, R1003, R1004, R1005, R1007, R1009, R1010, R1011, R1012, R1013, R1015, R1017, R1018, R1019, R1020, R1021, R1023, R1025, R1026, R1027, R1028, R1029, R1031, R1033, R1034, R1035, R1036, R1037, R1039, R1041, R1042, R1043, R1044, R1045, R1047, R1049, R1050, R1051, R1052, R1053, R1055, R1057, R1058, R1059, R1060, R1061, R1063, R1065, R1066, R1067, R1068, R1069, R1071, R1073, R1074, R1075, R1076, R1077, R1079, R1081, R1082, R1083, R1084, R1085, R1087, R1089, R1090, R1091, R1092, R1093, R1095, R1097, R1098, R1099, R1100, R1101, R1103, R1105, R1106, R1107, R1108, R1109, R1111, R1113, R1114, R1115, R1116, R1117, R1119, R1121, R1122, R1123, R1124, R1125, R1127, R1129, R1130, R1131, R1132, R1133, R1135, R1137, R1138, R1139, R1140, R1141, R1143, R1145, R1146, R1147, R1148, R1149, R1151, R1153, R1154, R1155, R1156, R1157, R1159, R1161, R1162, R1163, R1164, R1165, R1167, R1169, R1170, R1171, R1172, R1173, R1175, R1177, R1178, R1179, R1180, R1181, R1183, R1185, R1186, R1187, R1188, R1189, R1191, R1193, R1194, R1195, R1196, R1197, R1199, R1201, R1202, R1203, R1204, R1205, R1207, R1209, R1210, R1211, R1212, R1213, R1215, R1217, R1218, R1219, R1220, R1221, R1223, R1225, R1226, R1227, R1228, R1229, R1231, R1233, R1234, R1235, R1236, R1237, R1239, R1241, R1242, R1243, R1244, R1245, R1247, R1249, R1250, R1251, R1252, R1253, R1255, R1257, R1258, R1259, R1260, R1261, R1263, R1265, R1266, R1267, R1268, R1269, R1271, R1273, R1274, R1275, R1276, R1277, R1279, R1281, R1282, R1283, R1284, R1285, R1287, R1289, R1290, R1291, R1292, R1293, R1295, R1297, R1298, R1299, R1300, R1301, R1303, R1305, R1306, R1307, R1308, R1309, R1311, R1313, R1314, R1315, R1316, R1317, R1319, R1321, R1322, R1323, R1324, R1325, R1327, R1329, R1330, R1331, R1332, R1333, R1335, R1337, R1338, R1339, R1340, R1341, R1343: 10K; 0603-RES
R5, R9, R14, R16, R22, R24, R30, R32, R38, R40, R46, R48, R54, R56, R62, R64, R70, R72, R78, R80, R86, R88, R94, R96, R102, R104, R110, R112, R118, R120, R126, R128, R134, R136, R142, R144, R150, R152, R158, R160, R166, R168, R174, R176, R182, R184, R190, R192, R198, R200, R206, R208, R214, R216, R222, R224, R230, R232, R238, R240, R246, R248, R254, R256, R262, R264, R270, R272, R278, R280, R286, R288, R294, R296, R302, R304, R310, R312, R318, R320, R326, R328, R334, R336, R342, R344, R350, R352, R358, R360, R366, R368, R374, R376, R382, R384, R390, R392, R398, R400, R406, R408, R414, R416, R422, R424, R430, R432, R438, R440, R446, R448, R454, R456, R462, R464, R470, R472, R478, R480, R486, R488, R494, R496, R502, R504, R510, R512, R518, R520, R526, R528, R534, R536, R542, R544, R550, R552, R558, R560, R566, R568, R574, R576, R582, R584, R590, R592, R598, R600, R606, R608, R614, R616, R622, R624, R630, R632, R638, R640, R646, R648, R654, R656, R662, R664, R670, R672, R678, R680, R686, R688, R694, R696, R702, R704, R710, R712, R718, R720, R726, R728, R734, R736, R742, R744, R750, R752, R758, R760, R766, R768, R774, R776, R782, R784, R790, R792, R798, R800, R806, R808, R814, R816, R822, R824, R830, R832, R838, R840, R846, R848, R854, R856, R862, R864, R870, R872, R878, R880, R886, R888, R894, R896, R902, R904, R910, R912, R918, R920, R926, R928, R934, R936, R942, R944, R950, R952, R958, R960, R966, R968, R974, R976, R982, R984, R990, R992, R998, R1000, R1006, R1008, R1014, R1016, R1022, R1024, R1030, R1032, R1038, R1040, R1046, R1048, R1054, R1056, R1062, R1064, R1070, R1072, R1078, R1080, R1086, R1088, R1094, R1096, R1102, R1104, R1110, R1112, R1118, R1120, R1126, R1128, R1134, R1136, R1142, R1144, R1150, R1152, R1158, R1160, R1166, R1168, R1174, R1176, R1182, R1184, R1190, R1192, R1198, R1200, R1206, R1208, R1214, R1216, R1222, R1224, R1230, R1232, R1238, R1240, R1246, R1248, R1254, R1256, R1262, R1264, R1270, R1272, R1278, R1280, R1286, R1288, R1294, R1296, R1302, R1304, R1310, R1312, R1318, R1320, R1326, R1328, R1334, R1336, R1342, R1344: 20K; 0603-RES
U$1, U$3, U$5, U$7, U$9, U$11, U$13, U$15, U$17, U$19, U$21, U$23, U$25, U$27, U$29, U$31, U$33, U$35, U$37, U$39, U$41, U$43, U$45, U$47, U$49, U$51, U$53, U$55, U$57, U$59, U$61, U$63, U$65, U$67, U$69, U$71, U$73, U$75, U$77, U$79, U$81, U$83, U$85, U$87, U$89, U$91, U$93, U$95, U$97, U$99, U$101, U$103, U$105, U$107, U$109, U$111, U$113, U$115, U$117, U$119, U$121, U$123, U$125, U$127, U$129, U$131, U$133, U$135, U$137, U$139, U$141, U$143, U$145, U$147, U$149, U$151, U$153, U$155, U$157, U$159, U$161, U$163, U$165, U$167, U$169, U$171, U$173, U$175, U$177, U$179, U$181, U$183, U$185, U$187, U$189, U$191, U$193, U$195, U$197, U$199, U$201, U$203, U$205, U$207, U$209, U$211, U$213, U$215, U$217, U$219, U$221, U$223, U$225, U$227, U$229, U$231, U$233, U$235, U$237, U$239, U$241, U$243, U$245, U$247, U$249, U$251, U$253, U$255, U$257, U$259, U$261, U$263, U$265, U$267, U$269, U$271, U$273, U$275, U$277, U$279, U$281, U$283, U$285, U$287, U$289, U$291, U$293, U$295, U$297, U$299, U$301, U$303, U$305, U$307, U$309, U$311, U$313, U$315, U$317, U$319, U$321, U$323, U$325, U$327, U$329, U$331, U$333, U$335: LOGO-SFESK; SFE-LOGO-FLAME
U$2, U$4, U$6, U$8, U$10, U$12, U$14, U$16, U$18, U$20, U$22, U$24, U$26, U$28, U$30, U$32, U$34, U$36, U$38, U$40, U$42, U$44, U$46, U$48, U$50, U$52, U$54, U$56, U$58, U$60, U$62, U$64, U$66, U$68, U$70, U$72, U$74, U$76, U$78, U$80, U$82, U$84, U$86, U$88, U$90, U$92, U$94, U$96, U$98, U$100, U$102, U$104, U$106, U$108, U$110, U$112, U$114, U$116, U$118, U$120, U$122, U$124, U$126, U$128, U$130, U$132, U$134, U$136, U$138, U$140, U$142, U$144, U$146, U$148, U$150, U$152, U$154, U$156, U$158, U$160, U$162, U$164, U$166, U$168, U$170, U$172, U$174, U$176, U$178, U$180, U$182, U$184, U$186, U$188, U$190, U$192, U$194, U$196, U$198, U$200, U$202, U$204, U$206, U$208, U$210, U$212, U$214, U$216, U$218, U$220, U$222, U$224, U$226, U$228, U$230, U$232, U$234, U$236, U$238, U$240, U$242, U$244, U$246, U$248, U$250, U$252, U$254, U$256, U$258, U$260, U$262, U$264, U$266, U$268, U$270, U$272, U$274, U$276, U$278, U$280, U$282, U$284, U$286, U$288, U$290, U$292, U$294, U$296, U$298, U$300, U$302, U$304, U$306, U$308, U$310, U$312, U$314, U$316, U$318, U$320, U$322, U$324, U$326, U$328, U$330, U$332, U$334, U$336: OSHW-LOGOS; OSHW-LOGO-S

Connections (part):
GND: JP1.3, JP2.4, R5.1, R9.1
GND1: JP6.3, JP7.4, R14.1, R16.1
GND2: JP11.3, JP12.4, R22.1, R24.1
GND3: JP16.3, JP17.4, R30.1, R32.1
GND4: JP21.3, JP22.4, R38.1, R40.1
GND5: JP26.3, JP27.4, R46.1, R48.1
GND6: JP31.3, JP32.4, R54.1, R56.1
GND7: JP36.3, JP37.4, R62.1, R64.1
GND8: JP41.3, JP42.4, R70.1, R72.1
GND9: JP46.3, JP47.4, R78.1, R80.1
GND10: JP51.3, JP52.4, R86.1, R88.1
GND11: JP56.3, JP57.4, R94.1, R96.1
GND12: JP61.3, JP62.4, R102.1, R104.1
GND13: JP66.3, JP67.4, R110.1, R112.1
GND14: JP71.3, JP72.4, R118.1, R120.1
GND15: JP76.3, JP77.4, R126.1, R128.1
GND16: JP81.3, JP82.4, R134.1, R136.1
GND17: JP86.3, JP87.4, R142.1, R144.1
GND18: JP91.3, JP92.4, R150.1, R152.1
GND19: JP96.3, JP97.4, R158.1, R160.1
GND20: JP101.3, JP102.4, R166.1, R168.1
GND21: JP106.3, JP107.4, R174.1, R176.1
GND22: JP111.3, JP112.4, R182.1, R184.1
GND23: JP116.3, JP117.4, R190.1, R192.1
GND24: JP121.3, JP122.4, R198.1, R200.1
GND25: JP126.3, JP127.4, R206.1, R208.1
GND26: JP131.3, JP132.4, R214.1, R216.1
GND27: JP136.3, JP137.4, R222.1, R224.1
GND28: JP141.3, JP142.4, R230.1, R232.1
GND29: JP146.3, JP147.4, R238.1, R240.1
GND30: JP151.3, JP152.4, R246.1, R248.1
GND31: JP156.3, JP157.4, R254.1, R256.1
GND32: JP161.3, JP162.4, R262.1, R264.1
GND33: JP166.3, JP167.4, R270.1, R272.1
GND34: JP171.3, JP172.4, R278.1, R280.1
GND35: JP176.3, JP177.4, R286.1, R288.1
GND36: JP181.3, JP182.4, R294.1, R296.1
GND37: JP186.3, JP187.4, R302.1, R304.1
GND38: JP191.3, JP192.4, R310.1, R312.1
GND39: JP196.3, JP197.4, R318.1, R320.1
GND40: JP201.3, JP202.4, R326.1, R328.1
GND41: JP206.3, JP207.4, R334.1, R336.1
GND42: JP211.3, JP212.4, R342.1, R344.1
GND43: JP216.3, JP217.4, R350.1, R352.1
GND44: JP221.3, JP222.4, R358.1, R360.1
GND45: JP226.3, JP227.4, R366.1, R368.1
GND46: JP231.3, JP232.4, R374.1, R376.1
GND47: JP236.3, JP237.4, R382.1, R384.1
GND48: JP241.3, JP242.4, R390.1, R392.1
GND49: JP246.3, JP247.4, R398.1, R400.1
GND50: JP251.3, JP252.4, R406.1, R408.1
GND51: JP256.3, JP257.4, R414.1, R416.1
GND52: JP261.3, JP262.4, R422.1, R424.1
GND53: JP266.3, JP267.4, R430.1, R432.1
GND54: JP271.3, JP272.4, R438.1, R440.1
GND55: JP276.3, JP277.4, R446.1, R448.1
GND56: JP281.3, JP282.4, R454.1, R456.1
GND57: JP286.3, JP287.4, R462.1, R464.1
GND58: JP291.3, JP292.4, R470.1, R472.1
GND59: JP296.3, JP297.4, R478.1, R480.1
GND60: JP301.3, JP302.4, R486.1, R488.1
GND61: JP306.3, JP307.4, R494.1, R496.1
GND62: JP311.3, JP312.4, R502.1, R504.1
GND63: JP316.3, JP317.4, R510.1, R512.1
GND64: JP321.3, JP322.4, R518.1, R520.1
GND65: JP326.3, JP327.4, R526.1, R528.1
GND66: JP331.3, JP332.4, R534.1, R536.1
GND67: JP336.3, JP337.4, R542.1, R544.1
GND68: JP341.3, JP342.4, R550.1, R552.1
GND69: JP346.3, JP347.4, R558.1, R560.1
GND70: JP351.3, JP352.4, R566.1, R568.1
GND71: JP356.3, JP357.4, R574.1, R576.1
GND72: JP361.3, JP362.4, R582.1, R584.1
GND73: JP366.3, JP367.4, R590.1, R592.1
GND74: JP371.3, JP372.4, R598.1, R600.1
GND75: JP376.3, JP377.4, R606.1, R608.1
GND76: JP381.3, JP382.4, R614.1, R616.1
GND77: JP386.3, JP387.4, R622.1, R624.1
GND78: JP391.3, JP392.4, R630.1, R632.1
GND79: JP396.3, JP397.4, R638.1, R640.1
GND80: JP401.3, JP402.4, R646.1, R648.1
GND81: JP406.3, JP407.4, R654.1, R656.1
GND82: JP411.3, JP412.4, R662.1, R664.1
GND83: JP416.3, JP417.4, R670.1, R672.1
GND84: JP421.3, JP422.4, R678.1, R680.1
GND85: JP426.3, JP427.4, R686.1, R688.1
GND86: JP431.3, JP432.4, R694.1, R696.1
GND87: JP436.3, JP437.4, R702.1, R704.1
GND88: JP441.3, JP442.4, R710.1, R712.1
GND89: JP446.3, JP447.4, R718.1, R720.1
GND90: JP451.3, JP452.4, R726.1, R728.1
GND91: JP456.3, JP457.4, R734.1, R736.1
GND92: JP461.3, JP462.4, R742.1, R744.1
GND93: JP466.3, JP467.4, R750.1, R752.1
GND94: JP471.3, JP472.4, R758.1, R760.1
GND95: JP476.3, JP477.4, R766.1, R768.1
GND96: JP481.3, JP482.4, R774.1, R776.1
GND97: JP486.3, JP487.4, R782.1, R784.1
GND98: JP491.3, JP492.4, R790.1, R792.1
GND99: JP496.3, JP497.4, R798.1, R800.1
GND100: JP501.3, JP502.4, R806.1, R808.1
GND101: JP506.3, JP507.4, R814.1, R816.1
GND102: JP511.3, JP512.4, R822.1, R824.1
GND103: JP516.3, JP517.4, R830.1, R832.1
GND104: JP521.3, JP522.4, R838.1, R840.1
GND105: JP526.3, JP527.4, R846.1, R848.1
GND106: JP531.3, JP532.4, R854.1, R856.1
GND107: JP536.3, JP537.4, R862.1, R864.1
GND108: JP541.3, JP542.4, R870.1, R872.1
GND109: JP546.3, JP547.4, R878.1, R880.1
GND110: JP551.3, JP552.4, R886.1, R888.1
GND111: JP556.3, JP557.4, R894.1, R896.1
GND112: JP561.3, JP562.4, R902.1, R904.1
GND113: JP566.3, JP567.4, R910.1, R912.1
GND114: JP571.3, JP572.4, R918.1, R920.1
GND115: JP576.3, JP577.4, R926.1, R928.1
GND116: JP581.3, JP582.4, R934.1, R936.1
GND117: JP586.3, JP587.4, R942.1, R944.1
GND118: JP591.3, JP592.4, R950.1, R952.1
GND119: JP596.3, JP597.4, R958.1, R960.1
GND120: JP601.3, JP602.4, R966.1, R968.1
GND121: JP606.3, JP607.4, R974.1, R976.1
GND122: JP611.3, JP612.4, R982.1, R984.1
GND123: JP616.3, JP617.4, R990.1, R992.1
GND124: JP621.3, JP622.4, R998.1, R1000.1
GND125: JP626.3, JP627.4, R1006.1, R1008.1
GND126: JP631.3, JP632.4, R1014.1, R1016.1
GND127: JP636.3, JP637.4, R1022.1, R1024.1
GND128: JP641.3, JP642.4, R1030.1, R1032.1
GND129: JP646.3, JP647.4, R1038.1, R1040.1
GND130: JP651.3, JP652.4, R1046.1, R1048.1
GND131: JP656.3, JP657.4, R1054.1, R1056.1
GND132: JP661.3, JP662.4, R1062.1, R1064.1
GND133: JP666.3, JP667.4, R1070.1, R1072.1
GND134: JP671.3, JP672.4, R1078.1, R1080.1
GND135: JP676.3, JP677.4, R1086.1, R1088.1
GND136: JP681.3, JP682.4, R1094.1, R1096.1
GND137: JP686.3, JP687.4, R1102.1, R1104.1
GND138: JP691.3, JP692.4, R1110.1, R1112.1
GND139: JP696.3, JP697.4, R1118.1, R1120.1
GND140: JP701.3, JP702.4, R1126.1, R1128.1
GND141: JP706.3, JP707.4, R1134.1, R1136.1
GND142: JP711.3, JP712.4, R1142.1, R1144.1
GND143: JP716.3, JP717.4, R1150.1, R1152.1
GND144: JP721.3, JP722.4, R1158.1, R1160.1
GND145: JP726.3, JP727.4, R1166.1, R1168.1
GND146: JP731.3, JP732.4, R1174.1, R1176.1
GND147: JP736.3, JP737.4, R1182.1, R1184.1
GND148: JP741.3, JP742.4, R1190.1, R1192.1
GND149: JP746.3, JP747.4, R1198.1, R1200.1
GND150: JP751.3, JP752.4, R1206.1, R1208.1
GND151: JP756.3, JP757.4, R1214.1, R1216.1
GND152: JP761.3, JP762.4, R1222.1, R1224.1
GND153: JP766.3, JP767.4, R1230.1, R1232.1
GND154: JP771.3, JP772.4, R1238.1, R1240.1
GND155: JP776.3, JP777.4, R1246.1, R1248.1
GND156: JP781.3, JP782.4, R1254.1, R1256.1
GND157: JP786.3, JP787.4, R1262.1, R1264.1
GND158: JP791.3, JP792.4, R1270.1, R1272.1
GND159: JP796.3, JP797.4, R1278.1, R1280.1
GND160: JP801.3, JP802.4, R1286.1, R1288.1
GND161: JP806.3, JP807.4, R1294.1, R1296.1
GND162: JP811.3, JP812.4, R1302.1, R1304.1
GND163: JP816.3, JP817.4, R1310.1, R1312.1
GND164: JP821.3, JP822.4, R1318.1, R1320.1
GND165: JP826.3, JP827.4, R1326.1, R1328.1
GND166: JP831.3, JP832.4, R1334.1, R1336.1
GND167: JP836.3, JP837.4, R1342.1, R1344.1
HV: JP2.3, R4.1, R7.1
HV1: JP7.3, R10.1, R12.1
HV2: JP12.3, R18.1, R20.1
HV3: JP17.3, R26.1, R28.1
HV4: JP22.3, R34.1, R36.1
HV5: JP27.3, R42.1, R44.1
HV6: JP32.3, R50.1, R52.1
HV7: JP37.3, R58.1, R60.1
HV8: JP42.3, R66.1, R68.1
HV9: JP47.3, R74.1, R76.1
HV10: JP52.3, R82.1, R84.1
HV11: JP57.3, R90.1, R92.1
HV12: JP62.3, R98.1, R100.1
HV13: JP67.3, R106.1, R108.1
HV14: JP72.3, R114.1, R116.1
HV15: JP77.3, R122.1, R124.1
HV16: JP82.3, R130.1, R132.1
HV17: JP87.3, R138.1, R140.1
HV18: JP92.3, R146.1, R148.1
HV19: JP97.3, R154.1, R156.1
HV20: JP102.3, R162.1, R164.1
HV21: JP107.3, R170.1, R172.1
HV22: JP112.3, R178.1, R180.1
HV23: JP117.3, R186.1, R188.1
HV24: JP122.3, R194.1, R196.1
HV25: JP127.3, R202.1, R204.1
HV26: JP132.3, R210.1, R212.1
HV27: JP137.3, R218.1, R220.1
HV28: JP142.3, R226.1, R228.1
HV29: JP147.3, R234.1, R236.1
HV30: JP152.3, R242.1, R244.1
HV31: JP157.3, R250.1, R252.1
HV32: JP162.3, R258.1, R260.1
HV33: JP167.3, R266.1, R268.1
HV34: JP172.3, R274.1, R276.1
HV35: JP177.3, R282.1, R284.1
HV36: JP182.3, R290.1, R292.1
HV37: JP187.3, R298.1, R300.1
HV38: JP192.3, R306.1, R308.1
HV39: JP197.3, R314.1, R316.1
HV40: JP202.3, R322.1, R324.1
HV41: JP207.3, R330.1, R332.1
HV42: JP212.3, R338.1, R340.1
HV43: JP217.3, R346.1, R348.1
HV44: JP222.3, R354.1, R356.1
HV45: JP227.3, R362.1, R364.1
HV46: JP232.3, R370.1, R372.1
HV47: JP237.3, R378.1, R380.1
HV48: JP242.3, R386.1, R388.1
HV49: JP247.3, R394.1, R396.1
HV50: JP252.3, R402.1, R404.1
HV51: JP257.3, R410.1, R412.1
HV52: JP262.3, R418.1, R420.1
HV53: JP267.3, R426.1, R428.1
HV54: JP272.3, R434.1, R436.1
HV55: JP277.3, R442.1, R444.1
HV56: JP282.3, R450.1, R452.1
HV57: JP287.3, R458.1, R460.1
HV58: JP292.3, R466.1, R468.1
HV59: JP297.3, R474.1, R476.1
HV60: JP302.3, R482.1, R484.1
HV61: JP307.3, R490.1, R492.1
HV62: JP312.3, R498.1, R500.1
HV63: JP317.3, R506.1, R508.1
HV64: JP322.3, R514.1, R516.1
HV65: JP327.3, R522.1, R524.1
HV66: JP332.3, R530.1, R532.1
HV67: JP337.3, R538.1, R540.1
HV68: JP342.3, R546.1, R548.1
HV69: JP347.3, R554.1, R556.1
HV70: JP352.3, R562.1, R564.1
HV71: JP357.3, R570.1, R572.1
HV72: JP362.3, R578.1, R580.1
HV73: JP367.3, R586.1, R588.1
HV74: JP372.3, R594.1, R596.1
HV75: JP377.3, R602.1, R604.1
HV76: JP382.3, R610.1, R612.1
HV77: JP387.3, R618.1, R620.1
HV78: JP392.3, R626.1, R628.1
HV79: JP397.3, R634.1, R636.1
HV80: JP402.3, R642.1, R644.1
HV81: JP407.3, R650.1, R652.1
HV82: JP412.3, R658.1, R660.1
HV83: JP417.3, R666.1, R668.1
HV84: JP422.3, R674.1, R676.1
HV85: JP427.3, R682.1, R684.1
HV86: JP432.3, R690.1, R692.1
HV87: JP437.3, R698.1, R700.1
HV88: JP442.3, R706.1, R708.1
HV89: JP447.3, R714.1, R716.1
HV90: JP452.3, R722.1, R724.1
HV91: JP457.3, R730.1, R732.1
HV92: JP462.3, R738.1, R740.1
HV93: JP467.3, R746.1, R748.1
HV94: JP472.3, R754.1, R756.1
HV95: JP477.3, R762.1, R764.1
HV96: JP482.3, R770.1, R772.1
HV97: JP487.3, R778.1, R780.1
HV98: JP492.3, R786.1, R788.1
HV99: JP497.3, R794.1, R796.1
HV100: JP502.3, R802.1, R804.1
HV101: JP507.3, R810.1, R812.1
HV102: JP512.3, R818.1, R820.1
HV103: JP517.3, R826.1, R828.1
HV104: JP522.3, R834.1, R836.1
HV105: JP527.3, R842.1, R844.1
HV106: JP532.3, R850.1, R852.1
HV107: JP537.3, R858.1, R860.1
HV108: JP542.3, R866.1, R868.1
HV109: JP547.3, R874.1, R876.1
HV110: JP552.3, R882.1, R884.1
HV111: JP557.3, R890.1, R892.1
HV112: JP562.3, R898.1, R900.1
HV113: JP567.3, R906.1, R908.1
HV114: JP572.3, R914.1, R916.1
HV115: JP577.3, R922.1, R924.1
HV116: JP582.3, R930.1, R932.1
HV117: JP587.3, R938.1, R940.1
HV118: JP592.3, R946.1, R948.1
HV119: JP597.3, R954.1, R956.1
HV120: JP602.3, R962.1, R964.1
HV121: JP607.3, R970.1, R972.1
HV122: JP612.3, R978.1, R980.1
HV123: JP617.3, R986.1, R988.1
HV124: JP622.3, R994.1, R996.1
HV125: JP627.3, R1002.1, R1004.1
HV126: JP632.3, R1010.1, R1012.1
HV127: JP637.3, R1018.1, R1020.1
HV128: JP642.3, R1026.1, R1028.1
HV129: JP647.3, R1034.1, R1036.1
HV130: JP652.3, R1042.1, R1044.1
HV131: JP657.3, R1050.1, R1052.1
HV132: JP662.3, R1058.1, R1060.1
HV133: JP667.3, R1066.1, R1068.1
HV134: JP672.3, R1074.1, R1076.1
HV135: JP677.3, R1082.1, R1084.1
HV136: JP682.3, R1090.1, R1092.1
HV137: JP687.3, R1098.1, R1100.1
HV138: JP692.3, R1106.1, R1108.1
HV139: JP697.3, R1114.1, R1116.1
HV140: JP702.3, R1122.1, R1124.1
HV141: JP707.3, R1130.1, R1132.1
HV142: JP712.3, R1138.1, R1140.1
HV143: JP717.3, R1146.1, R1148.1
HV144: JP722.3, R1154.1, R1156.1
HV145: JP727.3, R1162.1, R1164.1
HV146: JP732.3, R1170.1, R1172.1
HV147: JP737.3, R1178.1, R1180.1
HV148: JP742.3, R1186.1, R1188.1
HV149: JP747.3, R1194.1, R1196.1
HV150: JP752.3, R1202.1, R1204.1
HV151: JP757.3, R1210.1, R1212.1
HV152: JP762.3, R1218.1, R1220.1
HV153: JP767.3, R1226.1, R1228.1
HV154: JP772.3, R1234.1, R1236.1
HV155: JP777.3, R1242.1, R1244.1
HV156: JP782.3, R1250.1, R1252.1
HV157: JP787.3, R1258.1, R1260.1
HV158: JP792.3, R1266.1, R1268.1
HV159: JP797.3, R1274.1, R1276.1
HV160: JP802.3, R1282.1, R1284.1
HV161: JP807.3, R1290.1, R1292.1
HV162: JP812.3, R1298.1, R1300.1
HV163: JP817.3, R1306.1, R1308.1
HV164: JP822.3, R1314.1, R1316.1
HV165: JP827.3, R1322.1, R1324.1
HV166: JP832.3, R1330.1, R1332.1
HV167: JP837.3, R1338.1, R1340.1
LV: JP1.4, Q1.1, Q2.1, R3.1, R6.1
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

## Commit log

2013-06-13 Adding Board and Schematic Eagle Files v13
    Changed all resistor packages from 0402 to 0603. Nudged resistors,
    which caused minor trace re-routing. Also changed text font to Vector.
    Updated Sparkfun Logo and added the Open Hardware logo.
    [Logic_Level_Converter.brd, Logic_Level_Converter.sch]
2013-06-13 Schematic Cleanup and Gitignore
    Changed net labels to updated SFE standards.
    [Logic_Level_Converter.sch]
2013-06-24 Resistor Value Changes and Revision Code Update
    Changed the vales of r5 and r9 resistors from 10k to 20k. Added the
    revision # to the schematic.
    [Logic_Level_Converter.brd, Logic_Level_Converter.sch]
2013-06-26 Updated Voltage Table / Added Creative Commons/Rev
    Changed the Example Voltage table to reflect the new resistor values as
    well as added an equation for reference. Added the creative commons
    license and designed by/revised by names.
    [Logic_Level_Converter.brd, Logic_Level_Converter.sch]
2013-07-18 Created Panels
    Created Giant panel for MYDATA and smaller panels for manncorp
    [Logic_Level_Converter-GiantPanel-v13.brd]
2013-07-18 smaller panel
    here is the smaller panel
    [Logic_Level_Converter-Panel-v13.brd]
2013-09-20 Small typo updates to schematic.
    [Logic_Level_Converter.brd, Logic_Level_Converter.sch]

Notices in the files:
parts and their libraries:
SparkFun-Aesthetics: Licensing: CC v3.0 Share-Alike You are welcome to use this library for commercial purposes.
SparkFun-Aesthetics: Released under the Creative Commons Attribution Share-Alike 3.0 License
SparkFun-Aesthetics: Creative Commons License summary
